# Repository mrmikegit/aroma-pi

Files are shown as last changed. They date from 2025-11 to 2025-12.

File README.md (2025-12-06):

# Oil Diffuser Control System

A web-based control system for a waterless oil diffuser connected to an HVAC system, designed to run on Raspberry Pi 5.

## Features

- **HVAC Fan Monitoring**: Automatically detects when the HVAC blower fan is running
- **Smart Activation**: Waits 10 seconds after detecting HVAC fan before starting diffuser
- **Configurable Duty Cycles**: 10 different intensity levels (on/off time combinations)
- **Business Hours Control**: Optional scheduling to run only during specified hours
- **Real-time Status**: Live display of HVAC, pump, and fan states
- **Runtime Tracking**: Monitors and displays total runtime for pump and fan
- **Historical Chart**: 24-hour visualization of HVAC fan state
- **Persistent Settings**: All configurations saved and restored after reboot
- **Push Alerts**: Optional web push notifications (including iOS via Add to Home Screen) when the oil tank is empty or via manual test button

## Hardware Requirements

- Raspberry Pi 5
- GPIO Connections:
  - GPIO25: Air pump control (output)
  - GPIO24: 12V fan control (output)
  - GPIO16: HVAC blower fan state (input, no internal pulldown)

## Installation

1. **Update system packages:**
   ```bash
   sudo apt update
   sudo apt upgrade -y
   ```

2. **Install system dependencies:**
   ```bash
   sudo apt install python3-pip python3-venv python3-gpiozero python3-lgpio -y
   ```
   
   Note: `gpiozero` with the `lgpio` backend is required for Raspberry Pi 5 GPIO access.

3. **Create virtual environment and install dependencies:**
   ```bash
   # Create venv with system site packages (required for lgpio access)
   python3 -m venv --system-site-packages venv
   
   # Install Python dependencies
   ./venv/bin/pip install -r requirements.txt
   ```
   
   Or use the install script:
   ```bash
   ./install_deps.sh
   ```

4. **Set up GPIO permissions (if needed):**
   ```bash
   sudo usermod -a -G gpio $USER
   ```
   (Log out and back in for this to take effect)

5. **Configure GPIO16 pull resistor (required for HVAC detection):**
   
   GPIO16 has an internal pull-down resistor enabled by default. This must be disabled for the HVAC fan detection to work correctly.
   
   Edit the boot config file:
   ```bash
   sudo nano /boot/firmware/config.txt
   ```
   
   Add this line at the end of the `[all]` section:
   ```
   gpio=16=ip,pn
   ```
   
   This configures GPIO16 as an input (`ip`) with no pull resistor (`pn`).
   
   Save the file and reboot:
   ```bash
   sudo reboot
   ```
   
   Verify the configuration after reboot:
   ```bash
   pinctrl get 16
   ```
   You should see `pn` (not `pd`) in the output, confirming no pull resistor is enabled.

## Usage

1. **Start the application:**
   
   Easiest way (using the start script):
   ```bash
   ./start.sh
   ```
   
   Or using the virtual environment directly:
   ```bash
   ./venv/bin/python app.py
   ```
   
   Or activate the virtual environment first:
   ```bash
   source venv/bin/activate
   python app.py
   ```

2. **Access the web interface:**
   Open a web browser and navigate to:
   ```
   http://raspberry-pi-ip-address:8080
   ```
   Or if running locally:
   ```
   http://localhost:8080
   ```

3. **Configure the system:**
   - Enable/disable the aroma system
   - Select desired intensity (duty cycle)
   - Optionally enable business hours
   - Monitor real-time status and runtime

## Duty Cycles

The system supports 10 different intensity levels:

| On Time | Off Time | Intensity |
|---|---|---|
| 60s | 240s | Very Low  |
| 60s | 120s | Low |
| 60s | 90s | Medium-Low|
| 60s | 60s | Medium |
| 60s | 45s | Medium-High|
| 60s | 30s | High |
| 90s | 30s | Very High |
| 120s | 30s | Very High |
| 240s | 30s | Maximum |
| 360s | 30s | Maximum |

## Operation Logic

1. The system polls GPIO16 every 5 seconds to check HVAC fan state
2. When HVAC fan is detected (logic LOW), the system waits 10 seconds
3. After the delay, the diffuser starts operating with the selected duty cycle
4. The diffuser only runs when:
   - System is enabled
   - HVAC fan is running
   - Within business hours (if enabled)

## Auto-Start on Boot

To run the application automatically on boot, set up a systemd service:

1. **Copy the service file to systemd directory:**
   ```bash
   sudo cp aroma-pi.service /etc/systemd/system/
   ```

2. **Edit the service file to match your setup (if needed):**
   ```bash
   sudo nano /etc/systemd/system/aroma-pi.service
   ```
   
   Update the following if your paths are different:
   - `User=pi` - Change to your username if different
   - `WorkingDirectory=/home/pi/aroma-pi` - Change to your actual path
   - `ExecStart=/home/pi/aroma-pi/venv/bin/python` - Change to your venv path

3. **Reload systemd and enable the service:**
   ```bash
   sudo systemctl daemon-reload
   sudo systemctl enable aroma-pi.service
   ```

4. **Start the service:**
   ```bash
   sudo systemctl start aroma-pi.service
   ```

5. **Check service status:**
   ```bash
   sudo systemctl status aroma-pi.service
   ```

6. **View service logs (to debug GPIO issues):**
   ```bash
   sudo journalctl -u aroma-pi.service -f
   ```

**Useful commands:**
- Stop the service: `sudo systemctl stop aroma-pi.service`
- Restart the service: `sudo systemctl restart aroma-pi.service`
- Disable auto-start: `sudo systemctl disable aroma-pi.service`
- Check if service is enabled: `sudo systemctl is-enabled aroma-pi.service`

## Push Notifications

The app can send web push notifications (including iOS 16.4+ web push when the site is added to the home screen). Notifications are triggered automatically when the oil tank reaches 0% and can be tested via the “Send Test Notification” button in the Control Panel.

1. **HTTPS is required** (you already have this via Cloudflare Zero Trust tunnel). Browsers (especially iOS) only allow service workers and push notifications on secure origins.
2. **Install to Home Screen on iOS**: After opening the site in Safari, tap share → “Add to Home Screen”. Push notifications only work for installed web apps on iOS.
3. **Enable notifications in the UI**: Use the “Enable Notifications” button to grant permission and subscribe the current browser.
4. **VAPID keys**: On first run the server automatically generates a `vapid.json` file. You can replace it with your own keys if desired.
5. **Subscriptions**: Stored in `subscriptions.json`. If a device unregisters, stale subscriptions are removed automatically the next time a notification is sent.

Push endpoints exposed by the server:

- `GET /api/vapid-public-key` – returns the public VAPID key.
- `POST /api/subscribe` – stores a new push subscription (called by the browser).
- `POST /api/test_notification` – sends a test notification to all active subscribers.

If you change domains or certificates, users must re-enable notifications so the browser can create a new subscription.

## File Structure

```
aroma/
├── app.py              # Main Flask application
├── requirements.txt    # Python dependencies
├── start.sh            # Start script
├── install_deps.sh     # Dependency installation script
├── aroma-pi.service    # systemd service file
├── config.json         # Saved settings (auto-generated)
├── history.json        # HVAC history data (auto-generated)
├── vapid.json          # VAPID keys for push notifications (auto-generated)
├── subscriptions.json  # Push notification subscriptions (auto-generated)
├── test_hvac.py        # HVAC testing utility
├── test_push.py        # Push notification testing utility
├── templates/
│   └── index.html      # Web interface
└── static/
    ├── css/
    │   └── style.css   # Stylesheet
    ├── js/
    │   └── app.js      # Frontend JavaScript
    ├── sw.js           # Service worker for push notifications
    ├── manifest.json   # Web app manifest
    └── favicon.svg     # App icon
```

## API Endpoints

- `GET /` - Main web interface
- `GET /api/status` - Get current system status
- `GET /api/history` - Get HVAC history (last 24 hours)
- `GET /api/duty_cycles` - Get available duty cycles
- `POST /api/settings` - Update system settings
- `POST /api/reset_counters` - Reset runtime counters

## Troubleshooting

- **GPIO not working**: Ensure you have GPIO permissions and RPi.GPIO is installed
- **Web interface not accessible**: Check firewall settings and ensure port 8080 is open
- **Settings not persisting**: Check file permissions on `config.json` and `history.json`

## Development Mode

For development on a non-Raspberry Pi system, the application will use mock GPIO that prints to console instead of controlling actual pins.

## License

This project is provided as-is for personal use.

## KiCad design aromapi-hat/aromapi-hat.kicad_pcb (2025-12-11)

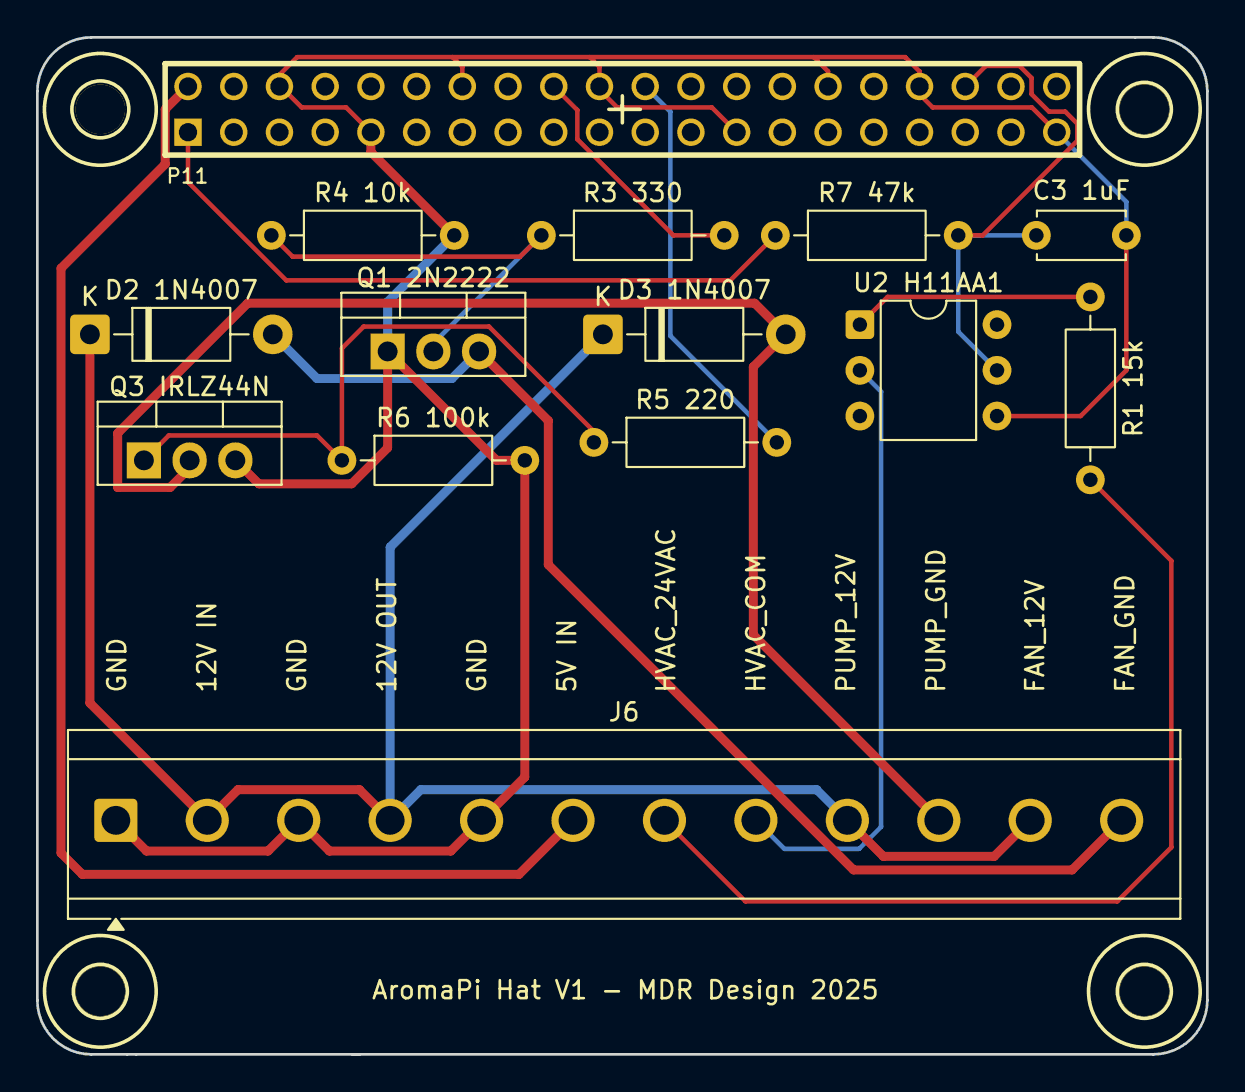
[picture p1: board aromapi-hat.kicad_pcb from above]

Board: 2 copper layers, 65.0 x 56.5 mm, 18 parts (0 on the bottom side), 14 nets.

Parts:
C3 1uF: 1uF; C_Disc_D4.7mm_W2.5mm_P5.00mm
D2 1N4007, D3 1N4007: 1N4007; D_DO-41_SOD81_P10.16mm_Horizontal
H1, H2, H3, H4: DRILL; dsk-drill-rpi-hat
J6: Screw_Terminal_01x12; TerminalBlock_CUI_TB007-508-12_1x12_P5.08mm_Horizontal
P11: CONN_20X2; PIN_ARRAY_20X2
Q1 2N2222: 2N2222; TO-220-3_Vertical
Q3 IRLZ44N: IRLZ44N; TO-220-3_Vertical
R1 15k: 15K; R_Axial_DIN0207_L6.3mm_D2.5mm_P10.16mm_Horizontal
R3 330: 330; R_Axial_DIN0207_L6.3mm_D2.5mm_P10.16mm_Horizontal
R4 10k: 10k; R_Axial_DIN0207_L6.3mm_D2.5mm_P10.16mm_Horizontal
R5 220: 100; R_Axial_DIN0207_L6.3mm_D2.5mm_P10.16mm_Horizontal
R6 100k: 100k; R_Axial_DIN0207_L6.3mm_D2.5mm_P10.16mm_Horizontal
R7 47k: 47k; R_Axial_DIN0207_L6.3mm_D2.5mm_P10.16mm_Horizontal
U2 H11AA1: H11AA1; DIP-6_W7.62mm

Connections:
+3.3V: P11.1, R7 47k.1
+5V: J6.6, P11.2
+12V: D2 1N4007.1 (K), D3 1N4007.1 (K), J6.2, J6.4, J6.9, J6.11
Fan: D2 1N4007.2 (A), J6.12, Q1 2N2222.3 (C)
GND: C3 1uF.2, J6.1, J6.3, J6.5, P11.6, P11.9, P11.14, P11.20, P11.25, P11.30, P11.34, P11.39, Q1 2N2222.1 (E), Q3 IRLZ44N.3 (S), R4 10k.2, R6 100k.2, U2 H11AA1.4
GPIO16_HVAC: C3 1uF.1, P11.36, R7 47k.2, U2 H11AA1.5
GPIO24_FAN: P11.18, R3 330.2
GPIO25_PUMP: P11.22, R5 220.2
HVAC+: J6.7, R1 15k.2
HVAC-: J6.8, U2 H11AA1.2
unnamed: Q1 2N2222.2 (B), R3 330.1, R4 10k.1
unnamed: Q3 IRLZ44N.1 (G), R5 220.1, R6 100k.1
unnamed: R1 15k.1, U2 H11AA1.1
Pump: D3 1N4007.2 (A), J6.10, Q3 IRLZ44N.2 (D)

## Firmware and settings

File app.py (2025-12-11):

#!/usr/bin/env python3
"""
Waterless Oil Diffuser Control System for Raspberry Pi 5
Controls diffuser based on HVAC fan state with configurable duty cycles
"""

import json
import os
import threading
import time
import base64
from datetime import datetime, time as dt_time
from flask import Flask, render_template, jsonify, request, send_from_directory
from flask_cors import CORS

try:
    from pywebpush import webpush, WebPushException
    WEBPUSH_AVAILABLE = True
except ImportError:
    WEBPUSH_AVAILABLE = False
    print("Warning: pywebpush not available. Push notifications disabled.")

try:
    from cryptography.hazmat.primitives.asymmetric import ec
except ImportError:
    ec = None

# GPIO imports - use gpiozero for Pi 5 support, mock for development
try:
    from gpiozero import OutputDevice, InputDevice
    # Try to use lgpio pin factory for Raspberry Pi 5
    lgpio_imported = False
    try:
        import lgpio
        lgpio_imported = True
        # Add compatibility shim for old/new lgpio constant names
        # New lgpio uses SET_PULL_*, old uses SET_BIAS_*
        # gpiozero may expect old names, so create aliases
        if hasattr(lgpio, 'SET_PULL_NONE') and not hasattr(lgpio, 'SET_BIAS_DISABLE'):
            # New version - create old constant aliases for gpiozero compatibility
            lgpio.SET_BIAS_DISABLE = lgpio.SET_PULL_NONE
        elif hasattr(lgpio, 'SET_BIAS_DISABLE') and not hasattr(lgpio, 'SET_PULL_NONE'):
            # Old version - create new constant aliases
            lgpio.SET_PULL_NONE = lgpio.SET_BIAS_DISABLE
        
        if hasattr(lgpio, 'SET_PULL_UP') and not hasattr(lgpio, 'SET_BIAS_PULL_UP'):
            lgpio.SET_BIAS_PULL_UP = lgpio.SET_PULL_UP
        elif hasattr(lgpio, 'SET_BIAS_PULL_UP') and not hasattr(lgpio, 'SET_PULL_UP'):
            lgpio.SET_PULL_UP = lgpio.SET_BIAS_PULL_UP
        
        if hasattr(lgpio, 'SET_PULL_DOWN') and not hasattr(lgpio, 'SET_BIAS_PULL_DOWN'):
            lgpio.SET_BIAS_PULL_DOWN = lgpio.SET_PULL_DOWN
        elif hasattr(lgpio, 'SET_BIAS_PULL_DOWN') and not hasattr(lgpio, 'SET_PULL_DOWN'):
            lgpio.SET_PULL_DOWN = lgpio.SET_BIAS_PULL_DOWN
        
        from gpiozero.pins.lgpio import LGPIOFactory
        from gpiozero import Device
        Device.pin_factory = LGPIOFactory()
        print("Using lgpio pin factory for Raspberry Pi 5")
    except ImportError as e:
        # lgpio not available - check if system package exists
        print(f"lgpio not found in venv ({e})")
        import sys
        # Check if venv has system-site-packages enabled
        if hasattr(sys, 'real_prefix') or (hasattr(sys, 'base_prefix') and sys.base_prefix != sys.prefix):
            # We're in a venv
            import sysconfig
            if '--system-site-packages' not in sysconfig.get_config_var('CONFIG_ARGS') or '':
                print("WARNING: Virtual environment was not created with --system-site-packages")
                print("To fix, run:")
                print("  rm -rf venv")
                print("  python3 -m venv --system-site-packages venv")
                print("  ./venv/bin/pip install -r requirements.txt")
        
        # Try to add system paths manually
        try:
            import sys
            system_paths = [
                '/usr/lib/python3/dist-packages',
                f'/usr/lib/python3.{sys.version_info.minor}/dist-packages',
            ]
            for path in system_paths:
                if path not in sys.path:
                    sys.path.insert(0, path)
            # Try importing again
            import lgpio
            lgpio_imported = True
            print(f"Successfully imported lgpio from system packages")
        except Exception as e2:
            print(f"Could not import lgpio from system: {e2}")
            print("Install with: sudo apt install python3-lgpio -y")
            print("Then recreate venv: rm -rf venv && python3 -m venv --system-site-packages venv")
    except Exception as e:
        # Other error setting up lgpio factory
        print(f"Note: Could not set up lgpio pin factory ({e})")
    GPIO_AVAILABLE = True
except (ImportError, RuntimeError, OSError) as e:
    print(f"Warning: gpiozero not available ({e}), using mock GPIO")
    GPIO_AVAILABLE = False
    # Mock GPIO for development
    class MockOutputDevice:
        def __init__(self, pin):
            self.pin = pin
            self._value = False
        
        def on(self):
            print(f"Mock GPIO: Pin {self.pin} = ON")
            self._value = True
        
        def off(self):
            print(f"Mock GPIO: Pin {self.pin} = OFF")
            self._value = False
        
        def close(self):
            pass
    
    class MockInputDevice:
        def __init__(self, pin, pull_up=None):
            self.pin = pin
            # Mock: return False (LOW, fan on) for testing
            self._value = False
        
        @property
        def value(self):
            return 0  # LOW = fan on
        
        @property
        def is_active(self):
            return False  # LOW = active (fan on)
        
        def close(self):
            pass
    
    OutputDevice = MockOutputDevice
    InputDevice = MockInputDevice

app = Flask(__name__)
CORS(app)

# GPIO Pin Definitions
GPIO_PUMP = 25      # Air pump control
GPIO_FAN = 24       # 12V fan control
GPIO_HVAC = 16      # HVAC blower fan state (LOW = on, HIGH = off)

# Configuration file
CONFIG_FILE = 'config.json'
HISTORY_FILE = 'history.json'
SUBSCRIPTIONS_FILE = 'subscriptions.json'
VAPID_FILE = 'vapid.json'

vapid_private_key = None
vapid_public_key = None
subscriptions = []
SUBSCRIPTIONS_FILE = 'subscriptions.json'
VAPID_FILE = 'vapid.json'

# Duty cycle presets (on_time, off_time in seconds)
DUTY_CYCLES = {
    '60s_240s': (60, 240),
    '60s_210s': (60, 210),
    '60s_180s': (60, 180),
    '60s_150s': (60, 150),
    '60s_120s': (60, 120),
    '60s_90s': (60, 90),
    '60s_60s': (60, 60),
    '60s_45s': (60, 45),
    '60s_30s': (60, 30),
    '90s_30s': (90, 30),
    '120s_30s': (120, 30),
    '240s_30s': (240, 30),
    '360s_30s': (360, 30),
}

# Global state
state = {
    'enabled': False,
    'duty_cycle': '60s_120s',
    'business_hours_enabled': False,
    'business_hours_start': '09:00',
    'business_hours_end': '19:00',
    'oil_usage_rate_ml_per_hour': 10.0,
    'oil_bottle_capacity_ml': 150.0,
    'hvac_fan_state': False,
    'pump_on': False,
    'fan_on': False,
    'pump_runtime_minutes': 0,
    'fan_runtime_minutes': 0,
    'last_pump_start': None,
    'last_fan_start': None,
    'oil_alert_sent': False,
}

# Control flags
control_thread = None
last_config_save_time = None  # Track last periodic config save
monitoring_thread = None
stop_flag = threading.Event()
hvac_history = []  # List of (timestamp, state) tuples

# GPIO device objects
gpio_pump = None
gpio_fan = None
gpio_hvac = None
lgpio_handle = None  # lgpio handle for direct pin configuration

def load_config():
    """Load configuration from file"""
    global state
    if os.path.exists(CONFIG_FILE):
        try:
            with open(CONFIG_FILE, 'r') as f:
                saved_state = json.load(f)
                state.update(saved_state)
                print(f"Loaded config: {saved_state}")
        except Exception as e:
            print(f"Error loading config: {e}")
    # Ensure new keys exist
    if 'oil_alert_sent' not in state:
        state['oil_alert_sent'] = False

def base64url_encode(data: bytes) -> str:
    return base64.urlsafe_b64encode(data).rstrip(b'=').decode('utf-8')

def generate_vapid_keys():
    """Generate new VAPID key pair"""
    if ec is None:
        raise RuntimeError("cryptography package is required to generate VAPID keys")
    private_key = ec.generate_private_key(ec.SECP256R1())
    private_number = private_key.private_numbers().private_value.to_bytes(32, 'big')
    public_key = private_key.public_key()
    numbers = public_key.public_numbers()
    x = numbers.x.to_bytes(32, 'big')
    y = numbers.y.to_bytes(32, 'big')
    public_key_bytes = b'\x04' + x + y
    return {
        "privateKey": base64url_encode(private_number),
        "publicKey": base64url_encode(public_key_bytes)
    }

def load_vapid_keys():
    """Load or generate VAPID keys for push notifications"""
    global vapid_private_key, vapid_public_key
    if os.path.exists(VAPID_FILE):
        try:
            with open(VAPID_FILE) as f:
                data = json.load(f)
                vapid_private_key = data.get('privateKey')
                vapid_public_key = data.get('publicKey')
                if vapid_private_key and vapid_public_key:
                    print("Loaded VAPID keys")
                    return
        except Exception as e:
            print(f"Error loading VAPID keys: {e}")
    if WEBPUSH_AVAILABLE:
        try:
            keys = generate_vapid_keys()
            vapid_private_key = keys['privateKey']
            vapid_public_key = keys['publicKey']
            with open(VAPID_FILE, 'w') as f:
                json.dump(keys, f, indent=2)
            print("Generated new VAPID keys")
        except Exception as e:
            print(f"Error generating VAPID keys: {e}")
    else:
        print("VAPID keys unavailable (pywebpush missing)")

def load_subscriptions():
    """Load push subscriptions"""
    global subscriptions
    if os.path.exists(SUBSCRIPTIONS_FILE):
        try:
            with open(SUBSCRIPTIONS_FILE) as f:
                subscriptions = json.load(f)
                print(f"Loaded {len(subscriptions)} subscriptions")
        except Exception as e:
            print(f"Error loading subscriptions: {e}")
            subscriptions = []

def save_subscriptions():
    """Persist push subscriptions"""
    try:
        with open(SUBSCRIPTIONS_FILE, 'w') as f:
            json.dump(subscriptions, f)
    except Exception as e:
        print(f"Error saving subscriptions: {e}")

def send_push_notification(title, body):
    """Send push notification to all subscribers"""
    if not WEBPUSH_AVAILABLE or not vapid_private_key or not vapid_public_key:
        return
    if not subscriptions:
        return
    message = json.dumps({"title": title, "body": body, "url": "/"})
    to_remove = []
    for sub in subscriptions:
        try:
            webpush(
                subscription_info=sub,
                data=message,
                vapid_private_key=vapid_private_key,
                vapid_claims={"sub": "mailto:admin@example.com"}
            )
        except WebPushException as ex:
            if ex.response is not None and ex.response.status_code in (404, 410):
                to_remove.append(sub)
            print(f"Push error: {ex}")
        except Exception as e:
            print(f"Push error: {e}")
    if to_remove:
        for sub in to_remove:
            if sub in subscriptions:
                subscriptions.remove(sub)
        save_subscriptions()

def save_config():
    """Save configuration to file"""
    try:
        with open(CONFIG_FILE, 'w') as f:
            json.dump(state, f, indent=2)
    except Exception as e:
        print(f"Error saving config: {e}")

def load_history():
    """Load HVAC history from file"""
    global hvac_history
    if os.path.exists(HISTORY_FILE):
        try:
            with open(HISTORY_FILE, 'r') as f:
                data = json.load(f)
                hvac_history = [(datetime.fromisoformat(ts), s) for ts, s in data]
        except Exception as e:
            print(f"Error loading history: {e}")

def save_history():
    """Save HVAC history to file (keep last 24 hours)"""
    try:
        # Keep only last 24 hours
        cutoff = datetime.now().timestamp() - (24 * 3600)
        recent_history = [(ts.isoformat(), s) for ts, s in hvac_history 
                         if ts.timestamp() > cutoff]
        
        with open(HISTORY_FILE, 'w') as f:
            json.dump(recent_history, f, indent=2)
    except Exception as e:
        print(f"Error saving history: {e}")

def init_gpio():
    """Initialize GPIO pins"""
    global gpio_pump, gpio_fan, gpio_hvac, GPIO_AVAILABLE, lgpio_handle
    
    if not GPIO_AVAILABLE:
        return
    
    try:
        # Initialize output devices (pump and fan)
        gpio_pump = OutputDevice(GPIO_PUMP, active_high=True, initial_value=False)
        gpio_fan = OutputDevice(GPIO_FAN, active_high=True, initial_value=False)
        
        # Initialize input device (HVAC state) - no pull resistor
        # First, configure the pin using lgpio directly
        try:
            import lgpio
            handle = lgpio.gpiochip_open(0)
            
            # Claim GPIO16 as input
            lgpio.gpio_claim_input(handle, GPIO_HVAC)
            
            # Set GPIO16 to no pull resistor
            try:
                lgpio.gpio_set_pull(handle, GPIO_HVAC, lgpio.SET_PULL_NONE)
                print(f"GPIO{GPIO_HVAC} configured with SET_PULL_NONE via lgpio")
            except AttributeError:
                # Try alternative function name if gpio_set_pull doesn't exist
                try:
                    lgpio.gpio_set_pull_config(handle, GPIO_HVAC, lgpio.SET_PULL_NONE)
                    print(f"GPIO{GPIO_HVAC} configured with SET_PULL_NONE via lgpio (alt method)")
                except AttributeError:
                    print(f"Warning: Could not set pull resistor - using default configuration")
            
            # Store handle for direct reading
            # We'll use lgpio directly for reading since we've configured it manually
            # This avoids gpiozero's constant compatibility issues
            lgpio_handle = handle
            gpio_hvac = None  # We'll use lgpio directly for reading
            print(f"GPIO{GPIO_HVAC} configured, will use lgpio directly for reading")
        except ImportError:
            # lgpio not available, try with gpiozero's pull parameter
            print("lgpio not available, trying gpiozero pull parameter...")
            try:
                gpio_hvac = InputDevice(GPIO_HVAC, pull=None)
            except Exception as e:
                print(f"Warning: Could not set pull=None, trying alternative: {e}")
                from gpiozero.pins.native import NativeFactory
                factory = NativeFactory()
                gpio_hvac = InputDevice(GPIO_HVAC, pull=None, pin_factory=factory)
            lgpio_handle = None
        
        print(f"GPIO initialized: Pump={GPIO_PUMP}, Fan={GPIO_FAN}, HVAC={GPIO_HVAC}")
    except Exception as e:
        print(f"Error initializing GPIO: {e}")
        GPIO_AVAILABLE = False

def cleanup_gpio():
    """Cleanup GPIO pins"""
    global gpio_pump, gpio_fan, gpio_hvac, lgpio_handle
    
    if gpio_pump:
        gpio_pump.close()
        gpio_pump = None
    if gpio_fan:
        gpio_fan.close()
        gpio_fan = None
    if gpio_hvac:
        gpio_hvac.close()
        gpio_hvac = None
    if lgpio_handle is not None:
        try:
            import lgpio
            lgpio.gpiochip_close(lgpio_handle)
        except:
            pass
        lgpio_handle = None

def is_business_hours():
    """Check if current time is within business hours"""
    if not state['business_hours_enabled']:
        return True
    
    try:
        start_time = dt_time.fromisoformat(state['business_hours_start'])
        end_time = dt_time.fromisoformat(state['business_hours_end'])
        current_time = datetime.now().time()
        
        if start_time <= end_time:
            return start_time <= current_time <= end_time
        else:  # Span midnight
            return current_time >= start_time or current_time <= end_time
    except Exception as e:
        print(f"Error checking business hours: {e}")
        return True

def update_runtime_counters():
    """Update runtime counters based on current state"""
    now = datetime.now()
    
    if state['pump_on']:
        if state['last_pump_start']:
            # Accumulate time since last check (1 second intervals)
            elapsed = 1.0 / 60.0  # 1 second in minutes
            state['pump_runtime_minutes'] += elapsed
        else:
            # Just turned on, record start time
            state['last_pump_start'] = now
    else:
        # Just turned off, clear start time
        if state['last_pump_start']:
            state['last_pump_start'] = None
    
    if state['fan_on']:
        if state['last_fan_start']:
            # Accumulate time since last check (1 second intervals)
            elapsed = 1.0 / 60.0  # 1 second in minutes
            state['fan_runtime_minutes'] += elapsed
        else:
            # Just turned on, record start time
            state['last_fan_start'] = now
    else:
        # Just turned off, clear start time
        if state['last_fan_start']:
            state['last_fan_start'] = None

def set_pump(on):
    """Control the air pump"""
    global gpio_pump
    
    if state['pump_on'] == on:
        return  # No change needed
    
    if GPIO_AVAILABLE and gpio_pump:
        if on:
            gpio_pump.on()
        else:
            gpio_pump.off()
    
    state['pump_on'] = on
    if on and not state['last_pump_start']:
        state['last_pump_start'] = datetime.now()

def set_fan(on):
    """Control the 12V fan"""
    global gpio_fan
    
    if state['fan_on'] == on:
        return  # No change needed
    
    if GPIO_AVAILABLE and gpio_fan:
        if on:
            gpio_fan.on()
        else:
            gpio_fan.off()
    
    state['fan_on'] = on
    if on and not state['last_fan_start']:
        state['last_fan_start'] = datetime.now()

def read_hvac_state():
    """Read HVAC blower fan state (LOW = on, HIGH = off)"""
    global gpio_hvac, lgpio_handle
    
    if GPIO_AVAILABLE:
        if gpio_hvac:
            # Use gpiozero to read
            # gpiozero: value is 0 for LOW, 1 for HIGH
            # LOW (0) means HVAC fan is on
            return gpio_hvac.value == 0
        elif lgpio_handle is not None:
            # Use lgpio directly to read
            try:
                import lgpio
                raw_value = lgpio.gpio_read(lgpio_handle, GPIO_HVAC)
                return raw_value == 0  # LOW = on
            except:
                return False
    else:
        # Mock: return True for testing
        return True

def hvac_monitoring_thread():
    """Monitor HVAC fan state every 5 seconds"""
    global hvac_history
    
    hvac_detected = False
    hvac_detected_time = None
    
    while not stop_flag.is_set():
        try:
            hvac_state = read_hvac_state()
            state['hvac_fan_state'] = hvac_state
            
            # Record history
            hvac_history.append((datetime.now(), hvac_state))
            
            # Keep only last 24 hours in memory
            cutoff = datetime.now().timestamp() - (24 * 3600)
            hvac_history = [(ts, s) for ts, s in hvac_history 
                           if ts.timestamp() > cutoff]
            
            # Save history periodically (every 5 minutes)
            if len(hvac_history) % 60 == 0:
                save_history()
            
            # Detect HVAC fan turning on
            if hvac_state and not hvac_detected:
                hvac_detected = True
                hvac_detected_time = time.time()
            elif not hvac_state:
                hvac_detected = False
                hvac_detected_time = None
            
            time.sleep(5)
        except Exception as e:
            print(f"Error in HVAC monitoring: {e}")
            time.sleep(5)

def calculate_oil_remaining():
    """Calculate remaining oil percentage"""
    pump_runtime_hours = state['pump_runtime_minutes'] / 60.0
    oil_used_ml = pump_runtime_hours * state['oil_usage_rate_ml_per_hour']
    oil_remaining_ml = max(0, state['oil_bottle_capacity_ml'] - oil_used_ml)
    oil_percentage = (oil_remaining_ml / state['oil_bottle_capacity_ml'] * 100) if state['oil_bottle_capacity_ml'] > 0 else 0
    return oil_percentage, oil_remaining_ml
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

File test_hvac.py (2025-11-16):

#!/usr/bin/env python3
"""
Test script to read and display HVAC fan state from GPIO16
Reads the state every 5 seconds and displays it on screen
"""

import time
import sys

# GPIO Pin Definition
GPIO_HVAC = 16  # HVAC blower fan state (LOW = on, HIGH = off)

# Try to use gpiozero with lgpio
try:
    from gpiozero import InputDevice
    # Try to use lgpio pin factory for Raspberry Pi 5
    try:
        from gpiozero.pins.lgpio import LGPIOFactory
        from gpiozero import Device
        Device.pin_factory = LGPIOFactory()
        print("Using lgpio pin factory for Raspberry Pi 5")
    except (ImportError, Exception) as e:
        print(f"Note: Using default pin factory ({e})")
    
    GPIO_AVAILABLE = True
except (ImportError, RuntimeError, OSError) as e:
    print(f"Error: gpiozero not available ({e})")
    print("Make sure gpiozero and rpi-lgpio are installed")
    sys.exit(1)

# Global variables
gpio_hvac = None
lgpio_handle = None

def read_hvac_state():
    """Read HVAC blower fan state (LOW = on, HIGH = off)"""
    global gpio_hvac, lgpio_handle
    
    if gpio_hvac:
        # Use gpiozero to read
        # gpiozero: value is 0 for LOW, 1 for HIGH
        # LOW (0) means HVAC fan is on
        raw_value = gpio_hvac.value
        is_on = raw_value == 0
        return is_on, raw_value
    elif lgpio_handle is not None:
        # Use lgpio directly to read
        import lgpio
        raw_value = lgpio.gpio_read(lgpio_handle, GPIO_HVAC)
        is_on = raw_value == 0  # LOW = on
        return is_on, raw_value
    return None, None

def main():
    global gpio_hvac, lgpio_handle
    
    print("HVAC Fan State Test Script")
    print("=" * 50)
    print(f"Monitoring GPIO{GPIO_HVAC} (LOW = fan ON, HIGH = fan OFF)")
    print("Press Ctrl+C to stop")
    print("=" * 50)
    print()
    
    try:
        # Initialize input device (HVAC state) - no pull resistor
        print(f"Initializing GPIO{GPIO_HVAC} as input with no pull resistor...")
        
        # First, configure the pin using lgpio directly
        import lgpio
        handle = lgpio.gpiochip_open(0)
        
        # Claim GPIO16 as input
        lgpio.gpio_claim_input(handle, GPIO_HVAC)
        
        # Set GPIO16 to no pull resistor
        try:
            lgpio.gpio_set_pull(handle, GPIO_HVAC, lgpio.SET_PULL_NONE)
            print(f"✓ GPIO{GPIO_HVAC} configured with SET_PULL_NONE via lgpio")
        except AttributeError:
            # Try alternative function name if gpio_set_pull doesn't exist
            try:
                lgpio.gpio_set_pull_config(handle, GPIO_HVAC, lgpio.SET_PULL_NONE)
                print(f"✓ GPIO{GPIO_HVAC} configured with SET_PULL_NONE via lgpio (alt method)")
            except AttributeError:
                print(f"⚠ Could not set pull resistor - using default configuration")
        
        # Now create InputDevice (without pull parameter since lgpio pin factory may not support it)
        try:
            gpio_hvac = InputDevice(GPIO_HVAC)
            print("✓ InputDevice created successfully")
        except Exception as e:
            print(f"✗ Error creating InputDevice: {e}")
            print("Will use lgpio directly for reading...")
            gpio_hvac = None
        
        # Store handle for direct reading if needed
        lgpio_handle = handle
        
        print()
        print("Starting monitoring (every 5 seconds)...")
        print()
        
        iteration = 0
        while True:
            iteration += 1
            timestamp = time.strftime("%Y-%m-%d %H:%M:%S")
            
            # Read the state
            is_on, raw_value = read_hvac_state()
            
            if is_on is not None:
                status = "ON" if is_on else "OFF"
                raw_status = f"LOW (0)" if raw_value == 0 else f"HIGH (1)"
                print(f"[{timestamp}] #{iteration:4d} | State: {status:3s} | Raw: {raw_status:8s} | Pin Value: {raw_value}")
            else:
                print(f"[{timestamp}] #{iteration:4d} | Error reading GPIO state")
            
            time.sleep(5)
            
    except KeyboardInterrupt:
        print("\n\nStopped by user")
    except Exception as e:
        print(f"\n\nError: {e}")
        import traceback
        traceback.print_exc()
    finally:
        if 'gpio_hvac' in globals() and gpio_hvac:
            gpio_hvac.close()
        if 'lgpio_handle' in globals() and lgpio_handle is not None:
            try:
                import lgpio
                lgpio.gpiochip_close(lgpio_handle)
            except:
                pass
        print("GPIO cleaned up")

if __name__ == '__main__':
    main()

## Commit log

2025-12-06 feat: Configure HVAC GPIO to disable internal pull resistors using `lgpio.SET_BIAS_DISABLE` and remove `InputDevice` instantiation in tests.
2025-12-06 fix: Correctly configure GPIO16 pull resistor using `lgpio.gpio_set_pull` and add persistent configuration instructions to the README.
    [app.py, test_hvac.py]
2025-12-11 feat: add initial KiCad project for aromapi-hat and update app.py
    [aromapi-hat.kicad_pcb, aromapi-hat.kicad_sch]
